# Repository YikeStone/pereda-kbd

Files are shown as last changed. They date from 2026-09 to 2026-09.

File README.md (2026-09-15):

# Pereda

Pereda is a custom wireless mechanical keyboard designed for **Kailh Choc V1** switches.

It has **46 keys**, aggressive **column stagger**, and **column splay**. The key positions are designed around my finger length and natural finger-joint movement rather than a conventional keyboard layout.

Finished Product:
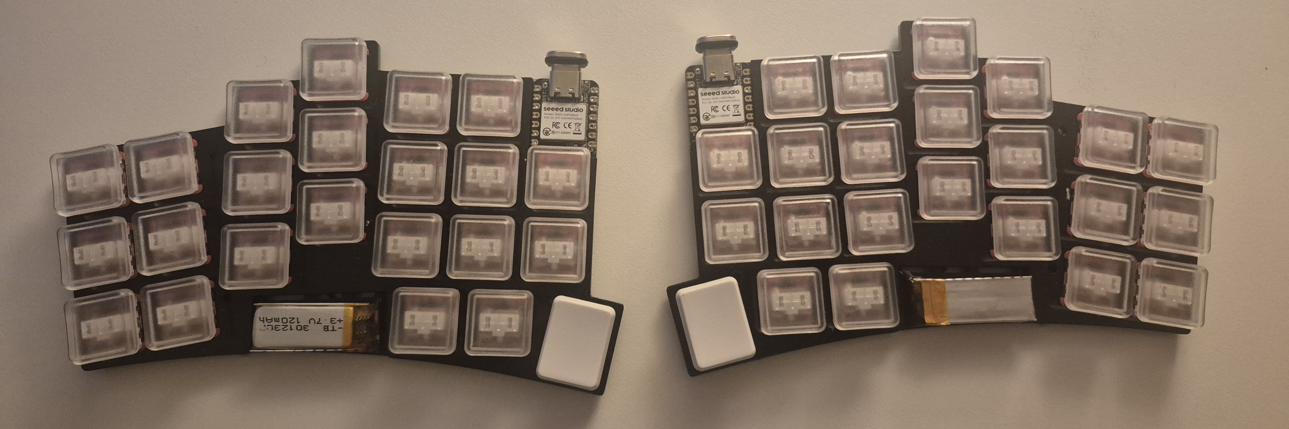
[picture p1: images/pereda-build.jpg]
Pereda Build


## Hardware

* Kailh Choc V1 switches
* Seeed Studio XIAO nRF52840
* Wireless
* 46 keys
* Aggressive column stagger and column splay
* Reversible PCB
* 301230 LiPo battery, 120 mAh
* Magnetic USB-C connector for charging
* Custom ergonomic key layout

## Build Details

* **Top plate:** 1 mm laser-cut aluminum, spray-painted black
* **PCB:** Black solder mask
* **Keyboard height:** ~1.5 cm from the table surface
* **Feet:** 8 × 3 mm silicone dots to prevent sliding

## Assembly

After soldering the XIAO nRF52840 module to the PCB, a battery pad on the underside of the XIAO remains accessible through the cutout in the PCB.

Solder the exposed battery pad on the XIAO to the corresponding battery pad on the PCB using a short wire.

The PCB is reversible, allowing the same PCB design to be used for either side.

## Firmware

Pereda uses **ZMK firmware**.

[Pereda ZMK Configuration](https://github.com/YikeStone/pereda-zmk)

## Manufacturing

Ready-to-manufacture files are available under:

`manufacturing/v0.2/`

The BOM quantities are for **one PCB/half**.

## Repository

* `common/` — custom symbols, footprints, and 3D models
* `images/` — project images
* `manufacturing/` — BOM, fabrication files, DXF, and CAD
* `*.kicad_*` — KiCad source files

## Status

**v0.2 — functional prototype.**

## Acknowledgements

Inspired by the [Corne keyboard](https://github.com/foostan/crkbd) by foostan.

## License

See `LICENSE`.

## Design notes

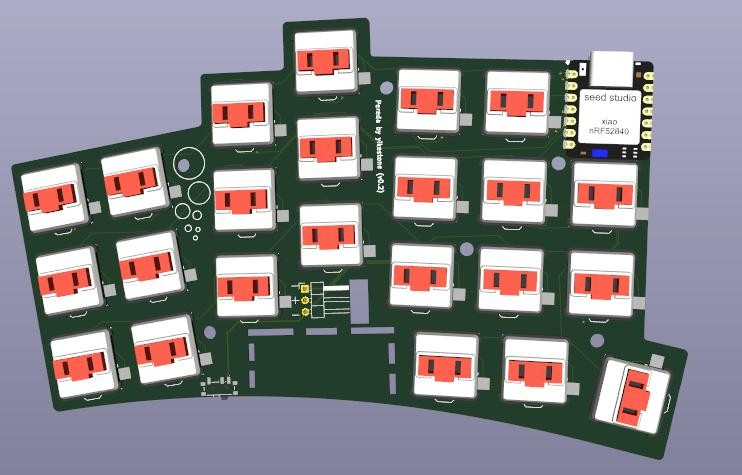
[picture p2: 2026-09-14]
images/pereda-choc-left.jpg

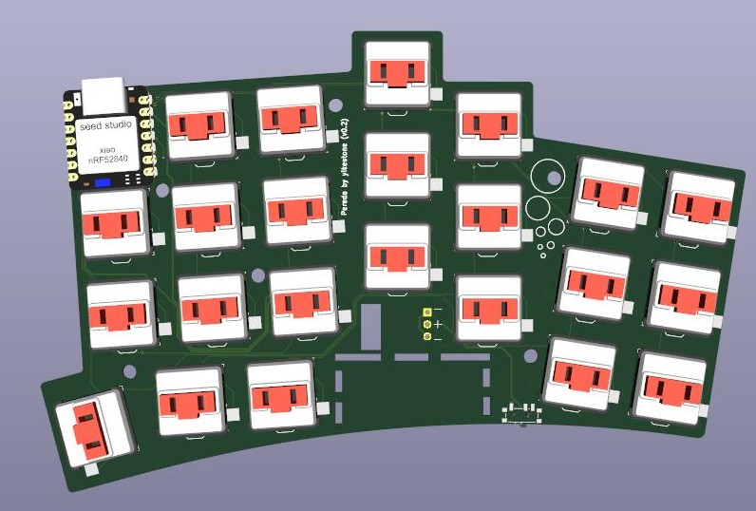
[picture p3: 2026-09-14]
images/pereda-choc-right.jpg

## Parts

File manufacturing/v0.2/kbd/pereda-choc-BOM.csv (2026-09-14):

Reference | Qty | Value | Exclude from BOM | Exclude from Board | MPN | Manufacturer
rSMDSW1,SMDSW2 | 1 | SPDT |  |  | PCM12SMTBR
rSW2,rSW3,rSW4,rSW5,rSW6,rSW7,rSW8,rSW9,rSW10,rSW11,rSW12,rSW13,rSW14,rSW15,rSW16,rSW17,rSW18,rSW19,rSW20,rSW21,rSW22,rSW23 | 22 | Kailh Choc v1 |  |  | 5118
rSW1 | 1 | Kailh Choc v1 |  |  | 5118
rU6,U1 | 1 | XIAO-nRF52840-SMD |  |  | 101991463 | Seeed Technology Co., Ltd
D2,D3,D4,D5,D6,D7,D8,D9,D10,D11,D12,D13,D14,D15,D16,D17,D18,D19,D20,D21,D22,D23,D24 | 23 | 1N4148WT |  |  | 1N4148W | Diotec Semiconductor

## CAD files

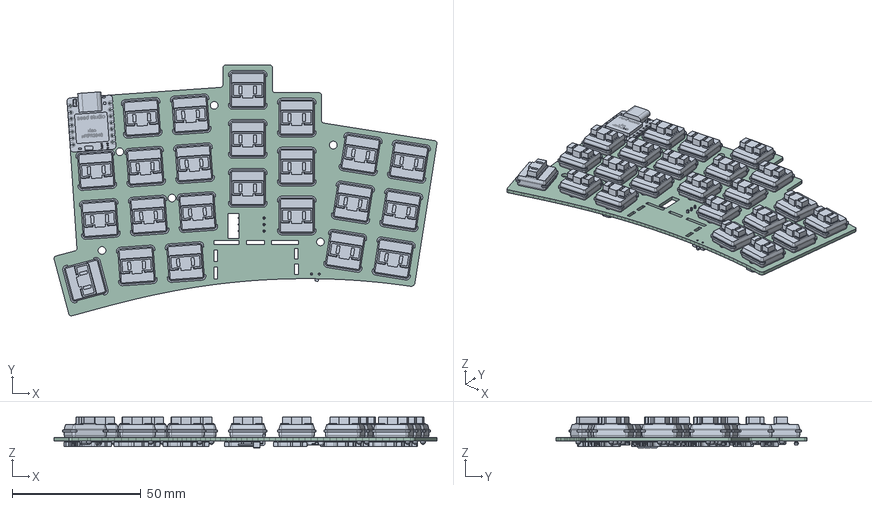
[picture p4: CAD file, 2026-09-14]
manufacturing/v0.2/assembly/pereda-right.step
148.9 x 97.5 x 12.0 mm
D_SOD-123 x 23
seed studio xiao nrg52840
kailh_choc_socket x 23
kailh_choc x 23
SW_SPDT_PCM12
PinHeader_1x03_P2.54mm_Horizontal
pereda-choc_PCB

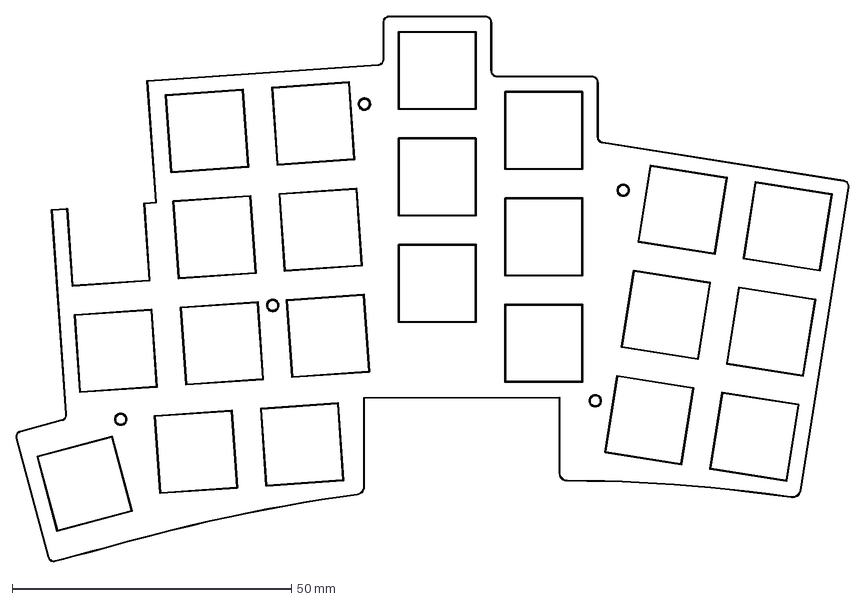
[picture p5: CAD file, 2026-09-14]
manufacturing/v0.2/top-plate/laser_cut/pereda-top-layer-Edge_Cuts.dxf
149.0 x 97.6 mm

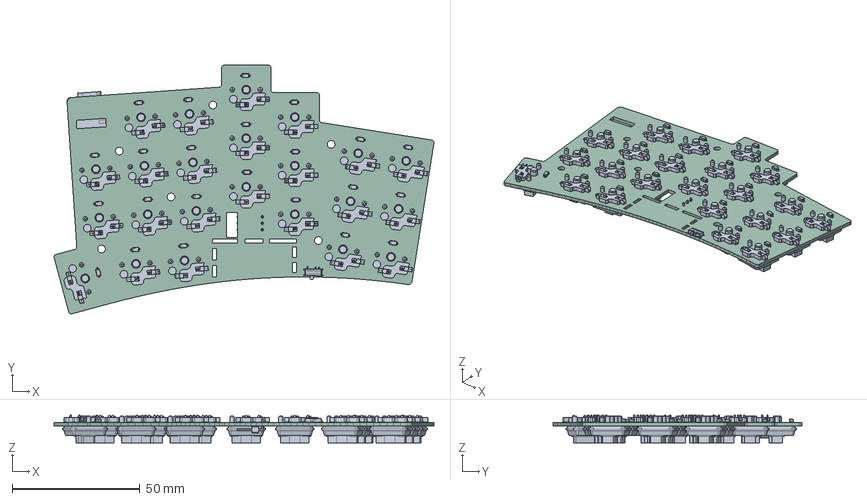
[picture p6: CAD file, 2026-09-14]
manufacturing/v0.2/assembly/pereda-left.step
148.9 x 97.5 x 10.9 mm
D_SOD-123 x 23
SW_SPDT_PCM12
kailh_choc_socket x 23
kailh_choc x 23
seed studio xiao nrg52840
PinHeader_1x03_P2.54mm_Horizontal
pereda-choc_PCB

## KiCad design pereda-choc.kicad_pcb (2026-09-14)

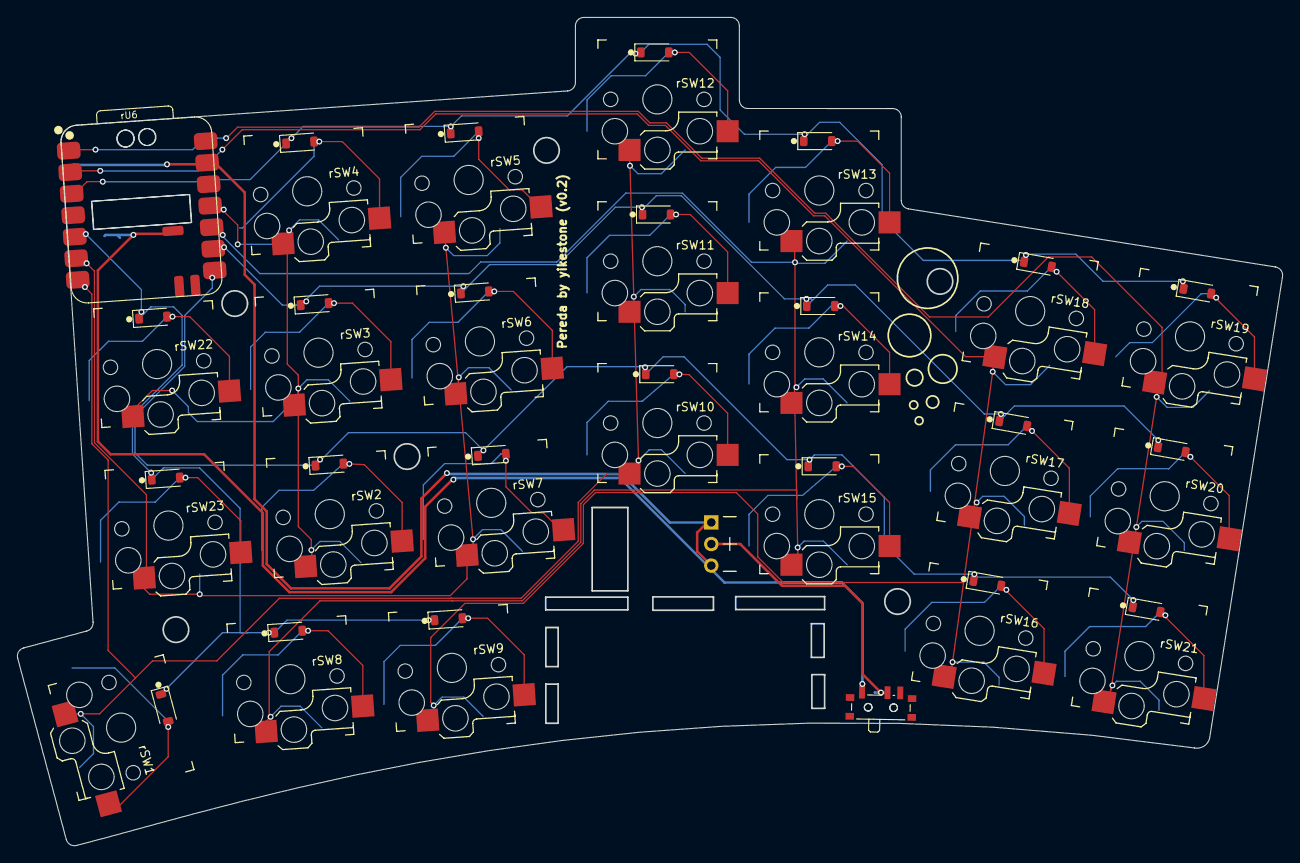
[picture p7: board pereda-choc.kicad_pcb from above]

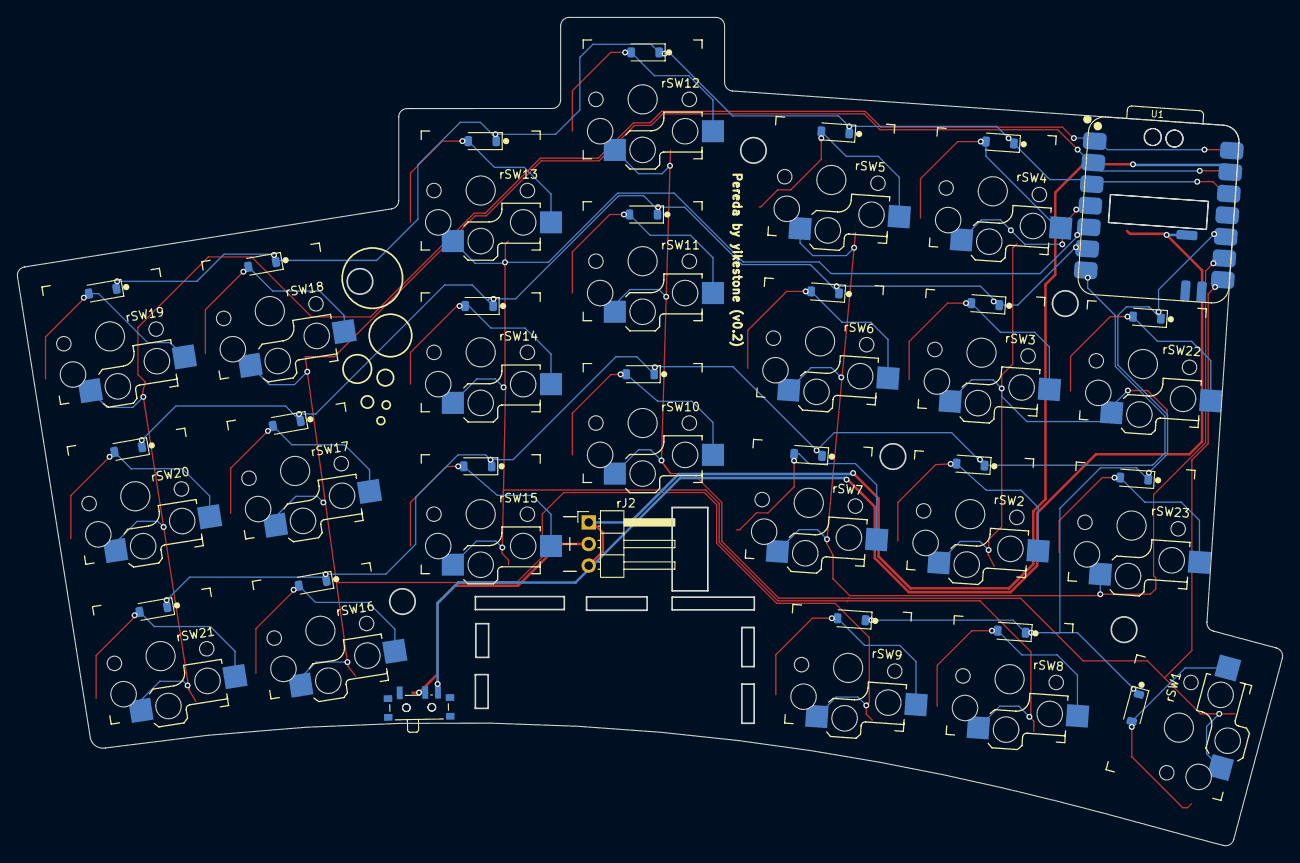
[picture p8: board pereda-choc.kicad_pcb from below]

Board: 2 copper layers, 148.9 x 97.5 mm, 51 parts (26 on the bottom side), 36 nets.

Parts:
D2, D3, D4, D5, D6, D7, D8, D9, D10, D11, D12, D13, D14, D15, D16, D17, D18, D19, D20, D21, D22, D23, D24: 1N4148WT; D_SOD-123-rev
SMDSW2: SPDT; SW_SPDT_PCM12
U1: XIAO-nRF52840-SMD; XIAO-nRF52840-SMD-kbd
rJ2: Conn_01x03; PinHeader_1x03_P2.54mm_Horizontal
rSMDSW1: SPDT; SW_SPDT_PCM12
rSW1: SW_Push; Kailh_socket_PG1350_reversible_1.25u
rSW2, rSW3, rSW4, rSW5, rSW6, rSW7, rSW8, rSW9, rSW10, rSW11, rSW12, rSW13, rSW14, rSW15, rSW16, rSW17, rSW18, rSW19, rSW20, rSW21, rSW22, rSW23: SW_Push; Kailh_socket_PG1350_reversible_1u
rU6: XIAO-nRF52840-SMD; XIAO-nRF52840-SMD-kbd

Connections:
COL0: U1.1 (P0.02_A0_D0), rSW19.1, rSW20.1, rSW21.1, rU6.1 (P0.02_A0_D0)
COL1: U1.2 (P0.03_A1_D1), rSW9.1, rSW16.1, rSW17.1, rSW18.1, rU6.2 (P0.03_A1_D1)
COL2: U1.5 (P0.04_A4_D4_SDA), rSW8.1, rSW13.1, rSW14.1, rSW15.1, rU6.10 (P1.14_D9_MISO)
COL3: U1.8 (P1.12_D7_RX), rSW1.1, rSW10.1, rSW11.1, rSW12.1, rU6.7 (P1.11_D6_TX)
COL4: U1.9 (P1.13_D8_SCK), rSW5.1, rSW6.1, rSW7.1, rSW23.1, rU6.6 (P0.05_A5_D5_SCL)
COL5: U1.4 (P0.29_A3_D3), rSW2.1, rSW3.1, rSW4.1, rSW22.1, rU6.11 (P1.15_D10_MOSI)
GND: U1.13 (GND), rJ2.1, rJ2.3, rU6.13 (GND)
unnamed: D2.2 (A), rSW4.2
unnamed: D3.2 (A), rSW5.2
unnamed: D4.2 (A), rSW12.2
unnamed: D5.2 (A), rSW13.2
unnamed: D6.2 (A), rSW18.2
unnamed: D7.2 (A), rSW19.2
unnamed: D8.2 (A), rSW20.2
unnamed: D9.2 (A), rSW21.2
unnamed: D10.2 (A), rSW16.2
unnamed: D11.2 (A), rSW9.2
unnamed: D12.2 (A), rSW17.2
unnamed: D13.2 (A), rSW14.2
unnamed: D14.2 (A), rSW11.2
unnamed: D15.2 (A), rSW6.2
unnamed: D16.2 (A), rSW3.2
unnamed: D17.2 (A), rSW2.2
unnamed: D18.2 (A), rSW22.2
unnamed: D19.2 (A), rSW23.2
unnamed: D20.2 (A), rSW1.2
unnamed: D21.2 (A), rSW7.2
unnamed: D22.2 (A), rSW10.2
unnamed: D23.2 (A), rSW8.2
unnamed: D24.2 (A), rSW15.2
POWER_ON: SMDSW2.2 (B), rJ2.2, rSMDSW1.2 (B)
ROW0: D2.1 (K), D3.1 (K), D4.1 (K), D5.1 (K), D6.1 (K), D7.1 (K), U1.3 (P0.28_A2_D2), rU6.3 (P0.28_A2_D2)
ROW1: D8.1 (K), D12.1 (K), D13.1 (K), D14.1 (K), D15.1 (K), D16.1 (K), U1.6 (P0.05_A5_D5_SCL), rU6.9 (P1.13_D8_SCK)
ROW2: D9.1 (K), D10.1 (K), D17.1 (K), D21.1 (K), D22.1 (K), D24.1 (K), U1.7 (P1.11_D6_TX), rU6.8 (P1.12_D7_RX)
ROW3: D11.1 (K), D18.1 (K), D19.1 (K), D20.1 (K), D23.1 (K), U1.10 (P1.14_D9_MISO), rU6.5 (P0.04_A4_D4_SDA)
VBAT: SMDSW2.1 (A), U1.19 (BAT), rSMDSW1.3 (A), rU6.19 (BAT)
